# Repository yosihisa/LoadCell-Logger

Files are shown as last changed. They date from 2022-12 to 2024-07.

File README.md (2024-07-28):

# LoadCell-Logger
4ch load cell logger board using Raspberry Pi Pico and HX711.  (Wakame Edition)

# ロードセルロガー
HX711とRaspberry Pi Picoを使用した4チャンネルロードセルロガーです。

# ソフトウェア開発環境

## 必要なもの
- Arduino IDE  
- 追加ボード [earlephilhower/arduino-pico](https://github.com/earlephilhower/arduino-pico) 

 Arduino公式のライブラリではマルチコアを使えないためこちら使用する。

## 設定方法 (環境構築)

### ①ボードの準備
ArduinoIDEの「ファイル」>「環境設定」から「追加のボードマネージャのURL」を開き以下のURLを追加する。
> https://github.com/earlephilhower/arduino-pico/releases/download/global/package_rp2040_index.json

ArduinoIDEの「ツール」> 「ボード」> 「ボードマネージャ」から `Raspberry Pi Pico/RP2040` をインストールする。

### ②ボードの設定  
ArduinoIDEから次のボードを設定する。  
`ボード` > `Raspberry Pi RP2040 Boards` > `Raspberry Pi Pico`  

コンパイルオプションは標準のままでよい。  
(Flash Size :2MB(noFS) , CPU Speed :125MHz , 各種デバッグ: 無効 , USB Stack: Pico SDK)

# 使い方 (暫定版)
## 必要なもの
- ソフト
  - TeraTermや[SerialMonitorEssential](https://github.com/771-8bit/SerialMonitorEssential)のようなシリアルモニタ

- ハード  
  - ロードセル
    - 基板上の端子台の表記を参考に接続する。色の意味は以下の通り。
        - 赤 : 印加電圧+
        - 黒 : 印加電圧-
        - 緑 : 出力信号+
        - 白 : 出力信号ｰ
  - USBケーブル
    - PCと接続する。電源もUSB経由で給電される。

## 使い方
1. LoadCell-Logger本体とPCをUSBで接続しシリアルモニタを起動する。  
   baudrate : 115200bps
2. シリアルモニタにカンマ区切りの12列のデータが自動で送られてくる。
   各データは左から1chから4chの順に並んでいる。
   - 1～4列目　ADC出力の生の値
   - 5～8列目　[gf]に換算した荷重　変換係数は[LoadCell-Logger.ino](src\LoadCell-Logger\LoadCell-Logger.ino)の先頭で定義されている。
   - 9～12列目　前回の表示から計測が更新された回数。1ならば正常。2以上の場合は読み飛ばしが発生している。
   - 13列目　外部出力信号の状態
   - 更新間隔　100Hz(10ms)ごとに1回(1行)更新される。
3. Aボタンを押すとオフセット調整ができる。
   - Aボタンを押した瞬間の値が原点として認識される。
   - ロードセルを荷重0の状態にしてAボタンを押すことで原点の調整が完了する。
4. シリアルモニタの機能を使用してログを記録する。
   - カンマ区切りのデータが出力されるので、そのままcsvファイルとして保存できる。

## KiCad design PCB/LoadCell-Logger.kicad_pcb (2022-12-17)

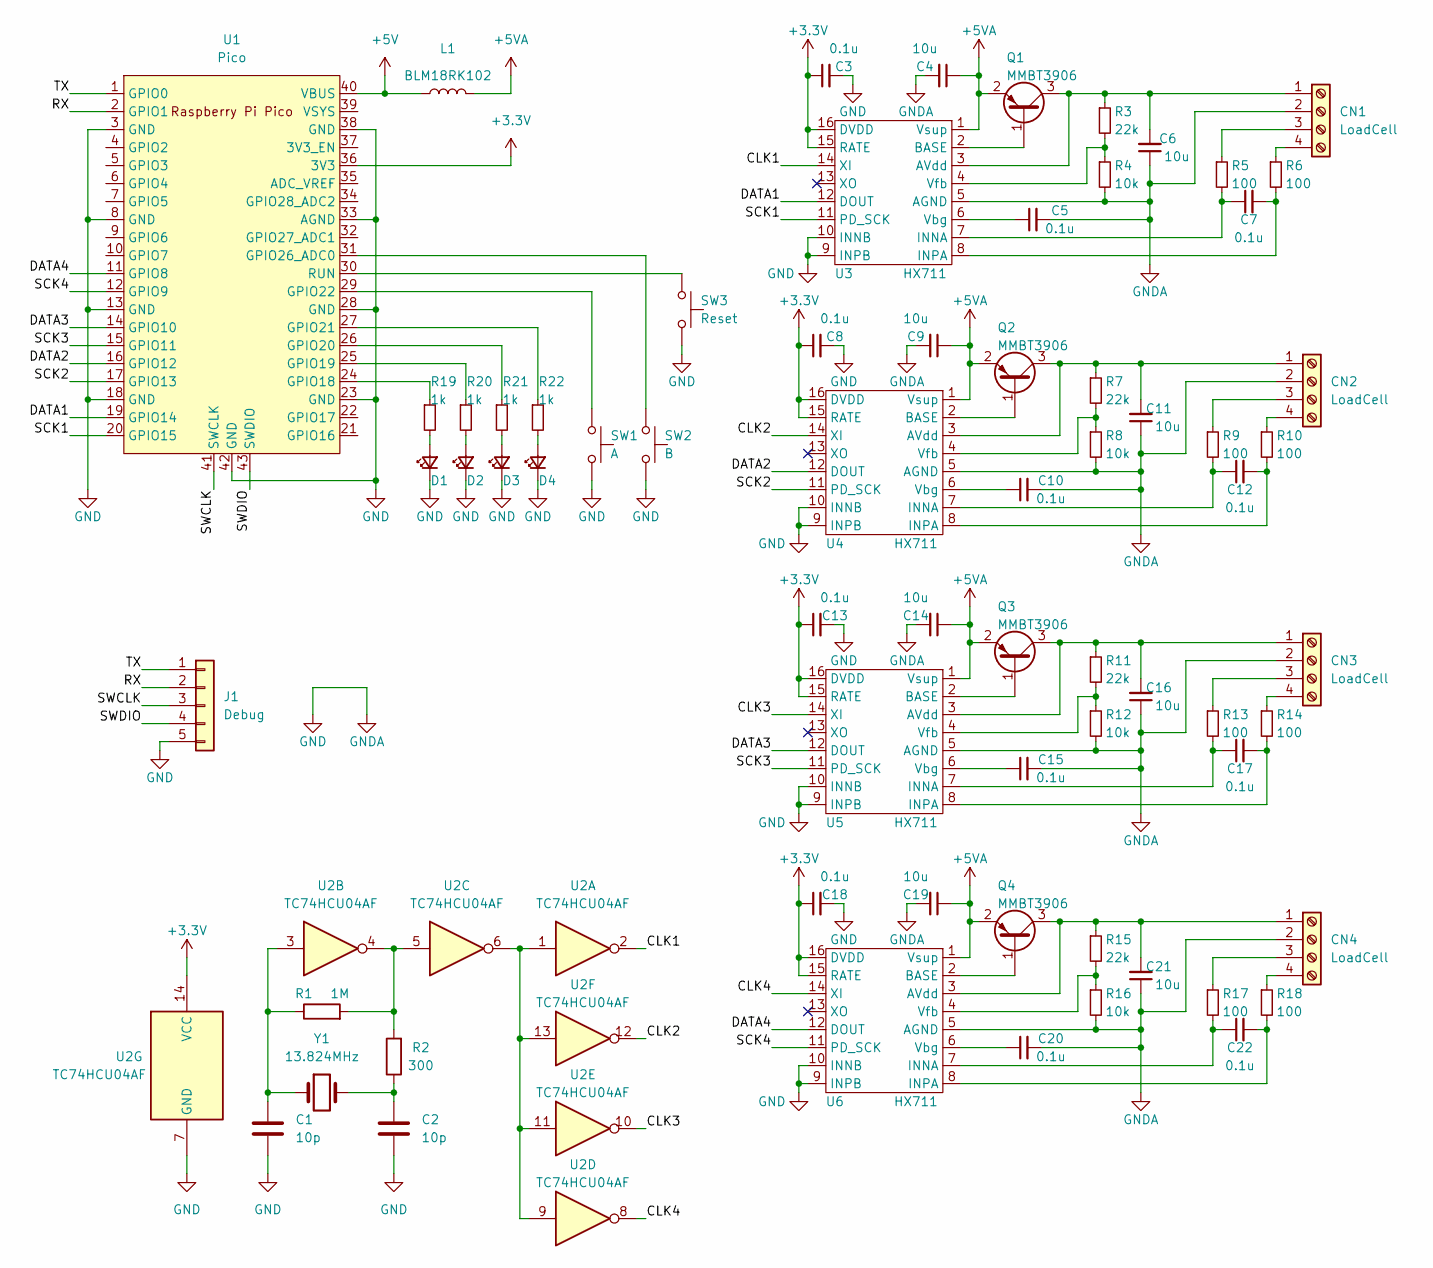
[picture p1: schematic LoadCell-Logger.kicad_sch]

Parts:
C1, C2: 10p; C_0603_1608Metric_Pad1.08x0.95mm_HandSolder
C3, C5, C7, C8, C10, C12, C13, C15, C17, C18, C20, C22: 0.1u; C_0603_1608Metric_Pad1.08x0.95mm_HandSolder
C4, C6, C9, C11, C14, C16, C19, C21: 10u; C_0805_2012Metric_Pad1.18x1.45mm_HandSolder
CN1, CN2, CN3, CN4: LoadCell; Molex_SPOX_5268-04A_1x04_P2.50mm_Horizontal
D1, D2, D3, D4: LED; LED_0603_1608Metric_Pad1.05x0.95mm_HandSolder
J1: Debug; STlink
L1: BLM18RK102; L_0603_1608Metric_Pad1.05x0.95mm_HandSolder
Q1, Q2, Q3, Q4: MMBT3906; SOT-23
R1: 1M; R_0805_2012Metric_Pad1.20x1.40mm_HandSolder
R2: 300; R_0603_1608Metric_Pad0.98x0.95mm_HandSolder
R3, R7, R11, R15: 22k; R_0603_1608Metric_Pad0.98x0.95mm_HandSolder
R4, R8, R12, R16: 10k; R_0603_1608Metric_Pad0.98x0.95mm_HandSolder
R5, R6, R9, R10, R13, R14, R17, R18: 100; R_0603_1608Metric_Pad0.98x0.95mm_HandSolder
R19, R20, R21, R22: 1k; R_0603_1608Metric_Pad0.98x0.95mm_HandSolder
SW1: A; SKRPACE010_kai
SW2: B; SKRPACE010_kai
SW3: Reset; SKRPACE010_kai
U1: Pico; RPi_Pico_SMD_TH
U2: TC74HCU04AF; SO-14_5.3x10.2mm_P1.27mm
U3, U4, U5, U6: HX711; SOP-16_3.9x9.9mm_P1.27mm
Y1: 13.824MHz; Crystal_HC49-U_Vertical

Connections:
+3V3: C3.1, C8.1, C13.1, C18.1, U1.36 (3V3), U2.14 (VCC), U3.15 (RATE), U3.16 (DVDD), U4.15 (RATE), U4.16 (DVDD), U5.15 (RATE), U5.16 (DVDD), U6.15 (RATE), U6.16 (DVDD)
+5V: L1.1, U1.40 (VBUS)
+5VA: C4.1, C9.1, C14.1, C19.1, L1.2, Q1.2 (E), Q2.2 (E), Q3.2 (E), Q4.2 (E), U3.1 (Vsup), U4.1 (Vsup), U5.1 (Vsup), U6.1 (Vsup)
/CLK1: U2.2, U3.14 (XI)
/CLK2: U2.12, U4.14 (XI)
/CLK3: U2.10, U5.14 (XI)
/CLK4: U2.8, U6.14 (XI)
/DATA1: U1.19 (GPIO14), U3.12 (DOUT)
/DATA2: U1.16 (GPIO12), U4.12 (DOUT)
/DATA3: U1.14 (GPIO10), U5.12 (DOUT)
/DATA4: U1.11 (GPIO8), U6.12 (DOUT)
/RX: J1.2, U1.2 (GPIO1)
/SCK1: U1.20 (GPIO15), U3.11 (PD_SCK)
/SCK2: U1.17 (GPIO13), U4.11 (PD_SCK)
/SCK3: U1.15 (GPIO11), U5.11 (PD_SCK)
/SCK4: U1.12 (GPIO9), U6.11 (PD_SCK)
/SWCLK: J1.3, U1.41 (SWCLK)
/SWDIO: J1.4, U1.43 (SWDIO)
/TX: J1.1, U1.1 (GPIO0)
GND: C1.2, C2.2, C3.2, C4.2, C5.2, C6.1, C8.2, C9.2, C10.2, C11.1, C13.2, C14.2, C15.2, C16.1, C18.2, C19.2, C20.2, C21.1, CN1.2, CN2.2, CN3.2, CN4.2, D1.1 (K), D2.1 (K), D3.1 (K), D4.1 (K), J1.5, R4.2, R8.2, R12.2, R16.2, SW1.2, SW2.2, SW3.2, U1.3 (GND), U1.8 (GND), U1.13 (GND), U1.18 (GND), U1.23 (GND), U1.28 (GND), U1.33 (AGND), U1.38 (GND), U1.42 (GND), U2.7 (GND), U3.5 (AGND), U3.9 (INPB), U3.10 (INNB), U4.5 (AGND), U4.9 (INPB), U4.10 (INNB), U5.5 (AGND), U5.9 (INPB), U5.10 (INNB), U6.5 (AGND), U6.9 (INPB), U6.10 (INNB)
unnamed: C1.1, R1.1, U2.3, Y1.1
unnamed: C2.1, R2.1, Y1.2
unnamed: C5.1, U3.6 (Vbg)
unnamed: C6.2, CN1.1, Q1.3 (C), R3.1, U3.3 (AVdd)
unnamed: C7.1, R5.2, U3.7 (INNA)
unnamed: C7.2, R6.2, U3.8 (INPA)
unnamed: C10.1, U4.6 (Vbg)
unnamed: C11.2, CN2.1, Q2.3 (C), R7.1, U4.3 (AVdd)
unnamed: C12.1, R9.2, U4.7 (INNA)
unnamed: C12.2, R10.2, U4.8 (INPA)
unnamed: C15.1, U5.6 (Vbg)
unnamed: C16.2, CN3.1, Q3.3 (C), R11.1, U5.3 (AVdd)
unnamed: C17.1, R13.2, U5.7 (INNA)
unnamed: C17.2, R14.2, U5.8 (INPA)
unnamed: C20.1, U6.6 (Vbg)
unnamed: C21.2, CN4.1, Q4.3 (C), R15.1, U6.3 (AVdd)
unnamed: C22.1, R17.2, U6.7 (INNA)
unnamed: C22.2, R18.2, U6.8 (INPA)
unnamed: CN1.3, R5.1
unnamed: CN1.4, R6.1
unnamed: CN2.3, R9.1
unnamed: CN2.4, R10.1
unnamed: CN3.3, R13.1
unnamed: CN3.4, R14.1
unnamed: CN4.3, R17.1
unnamed: CN4.4, R18.1
unnamed: D1.2 (A), R19.2
unnamed: D2.2 (A), R20.2
unnamed: D3.2 (A), R21.2
unnamed: D4.2 (A), R22.2
unnamed: Q1.1 (B), U3.2 (BASE)
unnamed: Q2.1 (B), U4.2 (BASE)
unnamed: Q3.1 (B), U5.2 (BASE)
unnamed: Q4.1 (B), U6.2 (BASE)
unnamed: R1.2, R2.2, U2.4, U2.5
unnamed: R3.2, R4.1, U3.4 (Vfb)
unnamed: R7.2, R8.1, U4.4 (Vfb)
unnamed: R11.2, R12.1, U5.4 (Vfb)
unnamed: R15.2, R16.1, U6.4 (Vfb)
unnamed: R19.1, U1.24 (GPIO18)
unnamed: R20.1, U1.25 (GPIO19)
unnamed: R21.1, U1.26 (GPIO20)
unnamed: R22.1, U1.27 (GPIO21)
unnamed: SW1.1, U1.29 (GPIO22)
unnamed: SW2.1, U1.31 (GPIO26_ADC0)
unnamed: SW3.1, U1.30 (RUN)
unnamed: U2.1, U2.6, U2.9, U2.11, U2.13

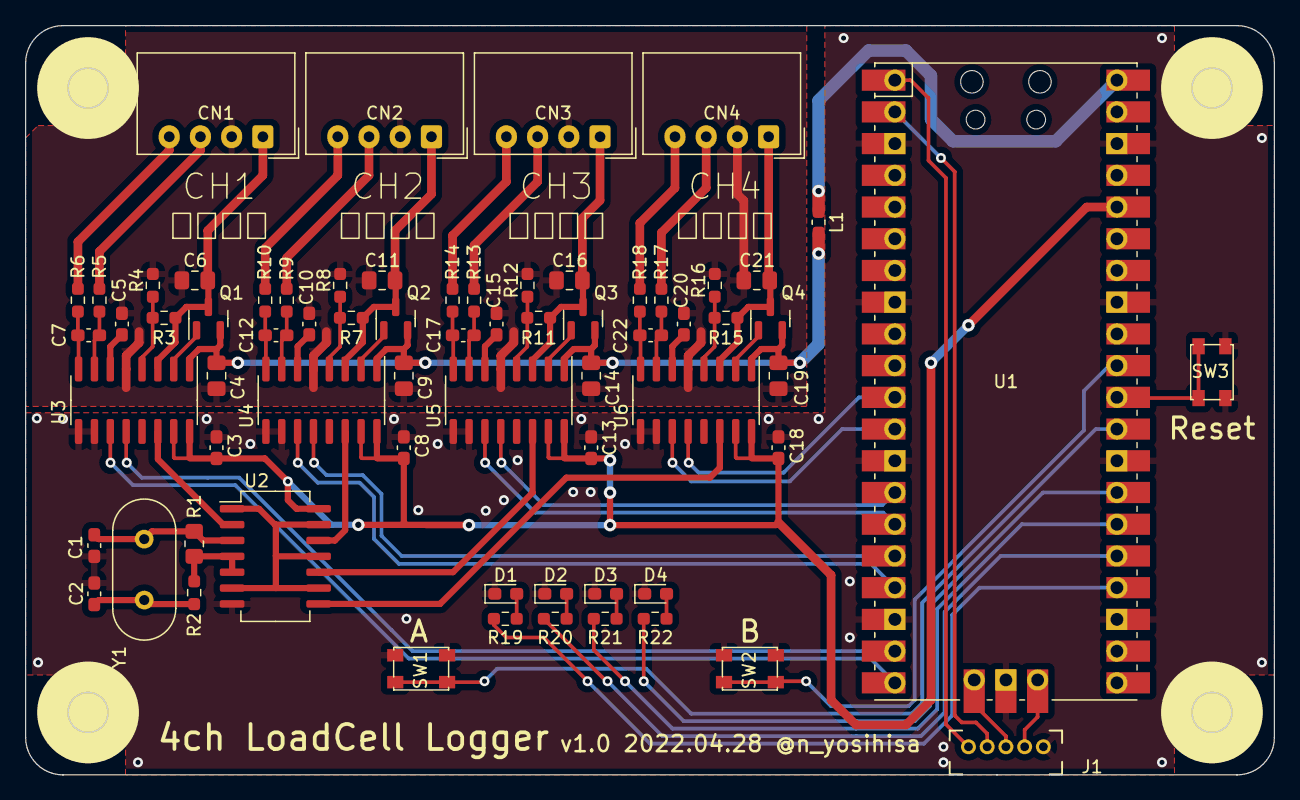
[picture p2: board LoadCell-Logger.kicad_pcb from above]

Board: 2 copper layers, 100.0 x 60.0 mm, 68 parts (0 on the bottom side), 67 nets.

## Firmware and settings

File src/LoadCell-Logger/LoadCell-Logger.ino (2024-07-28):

//---------------------------------------------------//
// ロードセル　シングルポイント（ ビーム型）　ＳＣ６０１　１２０ｋＧ [P-12035]
//---------------------------------------------------//
//#define OUT_VOL   0.001f      //定格出力 [V]
//#define LOAD      120000.0f   //定格容量 [g]

//---------------------------------------------------//
// ロードセル　シングルポイント（ ビーム型）　ＳＣ１３３　２０ｋＧ [P-12034]
//---------------------------------------------------//
#define OUT_VOL 0.002f  //定格出力 [V]
#define LOAD 20000.0f   //定格容量 [g]

//---------------------------------------------------//
// ロードセル　シングルポイント（ビーム型）　ＳＣ６１６Ｃ　５００ｇ[P-12532]
//---------------------------------------------------//
//#define OUT_VOL   0.0007f   //定格出力 [V]
//#define LOAD      500.0f    //定格容量 [g]


#define HX711_AVDD 4.000f  // ( 1.25*(( 22k + 10k )/ 10 ) )
#define HX711_ADC1bit ((HX711_AVDD / 16777216))
#define HX711_SCALE (OUT_VOL * HX711_AVDD / LOAD * 128)

#define OFFSET_AVERAGING 100

//----------ピン定義----------
#define CH1_DATA 14
#define CH1_SCK 15
#define CH2_DATA 12
#define CH2_SCK 13
#define CH3_DATA 10
#define CH3_SCK 11
#define CH4_DATA 8
#define CH4_SCK 9
#define LED1 18
#define LED2 19
#define LED3 20
#define LED4 21
#define SW_A 22
#define SW_B 26
#define PIN_TX 0
//----------ピン定義----------

#define NUM_CH 4
#define DOUT 0
#define SCK 1

int hx711_pin[NUM_CH][2] = {
  { CH1_DATA, CH1_SCK },
  { CH2_DATA, CH2_SCK },
  { CH3_DATA, CH3_SCK },
  { CH4_DATA, CH4_SCK }
};

enum HX711_State {
  HX711_RESET = 0,
  HX711_WAITING,
  HX711_READY
};

enum HX711_State hx711_state[NUM_CH];

enum State {
  READ = 0,
  SET_OFFSET
};

enum State state;

int32_t raw[NUM_CH] = { 0 };     //計測結果 生データ
int32_t offset[NUM_CH] = { 0 };  //オフセット
uint32_t read[NUM_CH] = { 0 };   //読み出し完了フラグ
uint32_t counter = 0;

void setup() {
  Serial.begin(115200);
  delay(1000);

  for (int i = 0; i < NUM_CH; i++) {
    pinMode(hx711_pin[i][DOUT], INPUT);
    pinMode(hx711_pin[i][SCK], OUTPUT);
  }

  pinMode(LED1, OUTPUT);
  pinMode(LED2, OUTPUT);
  pinMode(LED3, OUTPUT);
  pinMode(LED4, OUTPUT);
  pinMode(PIN_LED, OUTPUT);
  pinMode(PIN_TX, OUTPUT);

  pinMode(SW_A, INPUT_PULLUP);
  pinMode(SW_B, INPUT_PULLUP);


  // HX711 SCKをHIGHにしてリセット状態にする
  for (int i = 0; i < NUM_CH; i++) {
    digitalWrite(hx711_pin[i][SCK], HIGH);
  }

  digitalWrite(LED1, HIGH);
  digitalWrite(LED2, HIGH);
  digitalWrite(LED3, HIGH);
  digitalWrite(LED4, HIGH);

  state = READ;
}

void loop() {
  int32_t data[4];
  double gram[4];

  switch (state) {
    case READ:

      if ((read[0] != 0) & (read[1] != 0) & (read[2] != 0) & (read[3] != 0)) {
        for (int i = 0; i < NUM_CH; i++) {
          data[i] = raw[i] - offset[i];
          gram[i] = (double)data[i] * HX711_ADC1bit / HX711_SCALE;
        }

        digitalWrite(LED1, read[0] == 1);
        digitalWrite(LED2, read[1] == 1);
        digitalWrite(LED3, read[2] == 1);
        digitalWrite(LED4, read[3] == 1);

        uint8_t tx_state = (counter % 100) < 50 ? 1 : 0;
        digitalWrite(PIN_TX, tx_state);
        digitalWrite(PIN_LED, tx_state);

        Serial.printf("%+8d,%+8d,%+8d,%+8d,  %+12.5f,%+12.5f,%+12.5f,%+12.5f,  %d,%d,%d,%d, %c\n",
                      data[0], data[1], data[2], data[3],
                      gram[0], gram[1], gram[2], gram[3],
                      read[0], read[1], read[2], read[3],
                      tx_state == 1 ? 'H' : 'L');

        read[0] = 0;
        read[1] = 0;
        read[2] = 0;
        read[3] = 0;
        counter++;
      }

      if (digitalRead(SW_A) == LOW) {
        state = SET_OFFSET;
      }
      break;

    case SET_OFFSET:
      digitalWrite(PIN_LED, LOW);
      digitalWrite(LED1, LOW);
      digitalWrite(LED2, LOW);
      digitalWrite(LED3, LOW);
      digitalWrite(LED4, LOW);
      Serial.println("SET_OFFSET");
      for (int ch = 0; ch < NUM_CH; ch++) {
        offset[ch] = 0;
      }

      for (int i = 0; i < OFFSET_AVERAGING; i++) {
        for (int ch = 0; ch < NUM_CH; ch++) {
          offset[ch] += raw[ch];
        }
        delay(10);
      }

      for (int ch = 0; ch < NUM_CH; ch++) {
        offset[ch] = offset[ch] / OFFSET_AVERAGING;
      }

      state = READ;
      break;

    default:
      digitalWrite(PIN_LED, LOW);
      break;
  }
}



// core1は計測に専念させる
void setup1() {

  //core 0の初期化処理待ち
  delay(2000);


  // HX711 初期化
  // SCKをLOWにして計測を開始する
  for (int ch = 0; ch < NUM_CH; ch++) {
    read[ch] = 0;
    hx711_state[ch] = HX711_RESET;
    digitalWrite(hx711_pin[ch][SCK], LOW);
  }

  Serial.println("HX711 start!");
}

void loop1() {

  for (int ch = 0; ch < NUM_CH; ch++) {
    int32_t data = 0;

    switch (hx711_state[ch]) {

      // 初期状態 初回の計測が開始したら計測待機中へ
      // データシートには書かれてないが計測する瞬間にDOUTがHIGHになる
      case HX711_RESET:
        if (digitalRead(hx711_pin[ch][DOUT]) == HIGH) {
          //Serial.printf("%d start! \n",ch);
          hx711_state[ch] = HX711_WAITING;
        }
        break;

      // 計測待機中
      // DOUTがLOWになったら計測完了
      case HX711_WAITING:
        if (digitalRead(hx711_pin[ch][DOUT]) == LOW) {
          hx711_state[ch] = HX711_READY;
        }
        break;

      // 計測完了
      // データを読みだして次の計測待機へ
      case HX711_READY:

        for (int i = 0; i < 24; i++) {
          digitalWrite(hx711_pin[ch][SCK], HIGH);
          data = (data << 1) | (digitalRead(hx711_pin[ch][DOUT]));
          digitalWrite(hx711_pin[ch][SCK], LOW);
        }
        digitalWrite(hx711_pin[ch][SCK], HIGH);
        digitalWrite(hx711_pin[ch][SCK], LOW);

        raw[ch] = data ^ 0x800000;
        read[ch]++;
        hx711_state[ch] = HX711_WAITING;

        break;

      default:
        Serial.println("Error!");
        break;
    }
  }
}

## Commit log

2022-04-23 基板設計完了(初回)
    [LoadCell-Logger.kicad_pcb, LoadCell-Logger.kicad_sch]
2022-04-23 部品配置
    [LoadCell-Logger.kicad_pcb, LoadCell-Logger.kicad_sch]
2022-04-25 ロガー側配線完了
    [LoadCell-Logger.kicad_pcb, LoadCell-Logger.kicad_sch]
2022-04-28 基板設計完了
    [LoadCell-Logger.kicad_pcb, LoadCell-Logger.kicad_sch]
2022-04-28 最初の設計 (#1)
    [LoadCell-Logger.kicad_pcb, LoadCell-Logger.kicad_sch]
2022-12-17 デバッガー削除
    [LoadCell-Logger.kicad_pcb, LoadCell-Logger.kicad_sch]
2022-12-17 Revert "最初の設計 (#1)"
    This reverts commit 564b5e93a8b9a305720cbd9d862d9edbbbe04bbe.
    [LoadCell-Logger.kicad_pcb, LoadCell-Logger.kicad_sch]
2023-11-13 使い方(暫定版)追記
2024-07-28 同期用信号出力に対応
